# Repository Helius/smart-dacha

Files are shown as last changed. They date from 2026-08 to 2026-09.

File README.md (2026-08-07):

### Units
#### Top tank sensor
- esp32c3 with ext antenna
- uses wifi to publish self state to a mqtt broker
- no battery no outputs
- has an ultrasonic sensor and also a floating switch

#### Low tank unit
- esp32c3 with ext antenna
- reads ultrasonic sensor and controls a servo valve with sensors
- powered solely from battery (need to be optimized, or be solar powered)
- use esp-now to report self state to esp-now hub (see `valve & pump unit`)
  
#### Valve & pump unit
- esp32c3 with ext antenna
- uses wifi to publish self state and the low tank unit state to the mqtt broker
- serves also as esp-now hub for the low tank unit
- controls a servo valve with sensors and pump

### Notes
- esp-now uses the same channel as wifi - `8`, fix the channel on a router, it allows to be on both network with single esp32c3

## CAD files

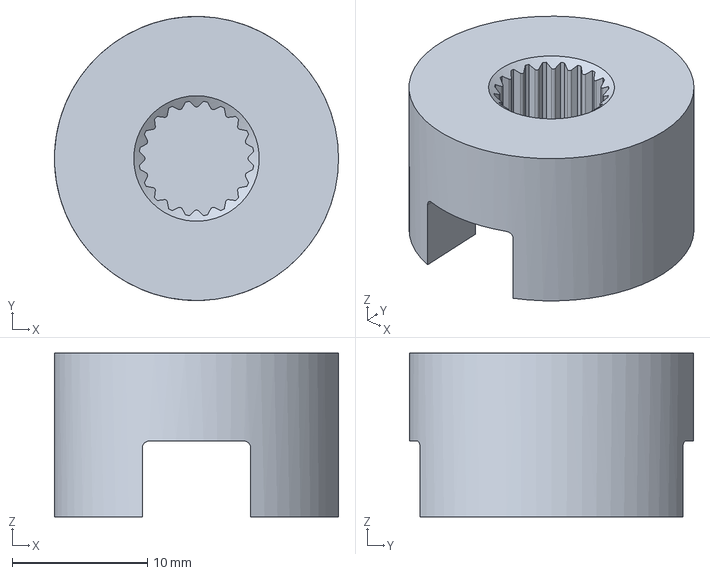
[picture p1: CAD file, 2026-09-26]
3d/servo-valve.FCStd
21.0 x 21.0 x 12.1 mm

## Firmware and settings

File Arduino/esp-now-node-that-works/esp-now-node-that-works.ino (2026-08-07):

#include <esp_now.h>
#include <WiFi.h>
#include <esp_wifi.h>
#include <ESP32Servo.h>

#include "DistanceMeter.h"

#define uS_TO_S_FACTOR 1000000ULL

#define LED_PIN 8
#define SERVO_PIN 3

#define AWAKE_BTN 2
#define ADC_PIN 4
#define SERVO_PWR_PIN 5
#define BUTTON_PIN 7
#define CLOSE_SENSOR 10
#define OPEN_SENSOR 6

uint8_t c6_mac[] = { 0x98, 0x88, 0xE0, 0x7F, 0x0A, 0x00 };  // Update this!

volatile bool replyReceived = false;
volatile int msgSend = 0;
Servo servo;

RTC_DATA_ATTR int rssi;
RTC_DATA_ATTR bool valveError = false;

float readBatteryVoltage() {
  analogSetAttenuation(ADC_11db);
  analogReadResolution(12);
  int raw = analogRead(ADC_PIN);
  return (raw / 4095.0) * 3.08 * 2.0;
}

int valveState() {
  auto open = !digitalRead(OPEN_SENSOR);
  auto close = !digitalRead(CLOSE_SENSOR);
  Serial.print("Valve sensor: ");
  Serial.print(open);
  Serial.println(close);
  if (!open && close) {
    return 0;
  } else if (open && !close) {
    return 1;
  }
  return -1;
}

// Updated callback for send status
void OnDataSent(const esp_now_send_info_t *tx_info, esp_now_send_status_t status) {

  if (status == ESP_NOW_SEND_SUCCESS) {
    msgSend = 2;
  } else {
    msgSend = 1;
  }
}

// Updated callback signature for newer API
void OnDataRecv(const esp_now_recv_info_t *info, const uint8_t *incomingData, int len) {
  char message[len + 1];
  memcpy(message, incomingData, len);
  message[len] = '\0';
  rssi = info->rx_ctrl->rssi;
  replyReceived = true;
}

bool sendAndReceive(byte *data, size_t len) {
  Serial.print("Sending: ");
  replyReceived = false;
  msgSend = 0;

  esp_err_t result = esp_now_send(c6_mac, data, len);

  if (result == ESP_OK) {
    Serial.print("OK, rssi: ");
    Serial.print(rssi);
  } else {
    Serial.print("F:");
    Serial.println(result);
    return false;
  }
  int attempts = 50;
  while ((msgSend == 0) && --attempts > 0) {
    if (msgSend == 1) {
      Serial.println(" can't send");
      return false;
    }
    delay(1);
  }

  if (msgSend != 2) {
    Serial.println(" send timeout");
    return false;
  }

  // just send

  // while (!replyReceived && attempts-- > 0) {
  //   delay(1);
  // }

  // if (!replyReceived) {
  //   Serial.println(" no reply");
  //   return false;
  // }

  return true;
}

void initRadio() {
  WiFi.mode(WIFI_STA);
  esp_wifi_set_max_tx_power(70);

  // 1. Force the Wi-Fi driver to start so channel changes take effect
  esp_wifi_start();

  // 2. Set WiFi channel to match your router (channel 8)
  esp_wifi_set_channel(8, WIFI_SECOND_CHAN_NONE);

  // 3. Verify the channel was actually set
  uint8_t primaryChan;
  wifi_second_chan_t secondChan;
  esp_wifi_get_channel(&primaryChan, &secondChan);
  Serial.print("Current Hardware Channel: ");
  Serial.println(primaryChan);

  Serial.print("C3 MAC: ");
  Serial.println(WiFi.macAddress());

  // Init ESP-NOW
  if (esp_now_init() != ESP_OK) {
    Serial.println("ESP-NOW init failed");
    return;
  }

  // Register callbacks
  esp_now_register_send_cb(OnDataSent);
  esp_now_register_recv_cb(OnDataRecv);

  // Add C6 as peer
  esp_now_peer_info_t peerInfo;
  memset(&peerInfo, 0, sizeof(peerInfo));
  memcpy(peerInfo.peer_addr, c6_mac, 6);
  peerInfo.channel = 8;
  //peerInfo.ifidx = WIFI_IF_STA;  // Changed from ESP_IF_WIFI_STA

  if (esp_now_add_peer(&peerInfo) != ESP_OK) {
    Serial.println("Failed to add C6 peer");
    return;
  }
}

void setup() {
  Serial.begin(115200);
  pinMode(LED_PIN, OUTPUT);
  pinMode(SERVO_PWR_PIN, INPUT);
  pinMode(AWAKE_BTN, INPUT_PULLUP);
  pinMode(BUTTON_PIN, INPUT_PULLUP);
  pinMode(OPEN_SENSOR, INPUT_PULLUP);
  pinMode(CLOSE_SENSOR, INPUT_PULLUP);

  esp_deep_sleep_enable_gpio_wakeup(1ULL << AWAKE_BTN, ESP_GPIO_WAKEUP_GPIO_LOW);
  Serial.println("C3 ready!");
}

void setValveOpen(bool open) {
  // TODO: check current servo valve and do nothing if it's already in state
  pinMode(SERVO_PWR_PIN, OUTPUT);
  digitalWrite(SERVO_PWR_PIN, LOW);
  Serial.print("Trun servo: ");
  Serial.println(open ? 90 : 0);
  servo.setPeriodHertz(50);
  servo.attach(SERVO_PIN, 500, 2400);
  servo.write(open ? 0 : 90);
  int attempts = 15;
  while (valveState() != (open ? 1 : 0) && attempts-- > 0) {
    Serial.println("wait servo to move");
    delay(100);
  }
  delay(100);

  if (attempts <= 0) {
    valveError = true;
  } else {
    valveError = false;
  }

  servo.detach();
  digitalWrite(SERVO_PWR_PIN, HIGH);
}

struct Packet {
  int8_t rssi;
  uint8_t bat;
  int8_t distance;
  uint8_t flags;
};

void loop() {
  static unsigned long lastSend = 0;
  digitalWrite(LED_PIN, LOW);

  for (int i = 0; i < SAMPLES_CNT; ++i) {
    measurements[i] = takeUltrasonicMeasurement();
  }

  int8_t distance = getMedian(measurements);
  uint8_t bat = readBatteryVoltage() * 10;

  // control valve
  if (distance == 0) {
    distance = -1;
  }

  if (bat < 36) {
    setValveOpen(false);
  } else {
    if (distance <= 15 && valveState() == 1) {
      setValveOpen(false);
    } else if (distance > 30 && valveState() == 0) {
      setValveOpen(true);
    }
  }

  initRadio();
  delay(10);

  Packet packet = {
    .rssi = rssi,
    .bat = bat,
    .distance = distance,
    .flags = (valveError << 1) | (valveState() == 1)
  };

  union Msg {
    Packet packet;
    byte arr[4];
  };

  Msg msg;
  msg.packet = packet;

  sendAndReceive(msg.arr, sizeof(msg.arr));

  if (valveState() == 1) {
    esp_sleep_enable_timer_wakeup(5 * uS_TO_S_FACTOR);
  } else {
    esp_sleep_enable_timer_wakeup(30 * uS_TO_S_FACTOR);
  }

  digitalWrite(LED_PIN, HIGH);
  if (!digitalRead(AWAKE_BTN)) {
    Serial.print(" Distance ");
    Serial.print(distance);

    Serial.print(", Bat ");
    Serial.print(bat);

    Serial.print(",rssi ");
    Serial.println(rssi);

    int vs = valveState();
    Serial.print("Valve state: ");
    Serial.print(vs);
    Serial.print(" valveError: ");
    Serial.print(valveError);

    delay(3000);
  } else {
    esp_deep_sleep_start();
  }

  delay(10);
}

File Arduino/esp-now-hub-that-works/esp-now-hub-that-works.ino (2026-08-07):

#include "esp32-hal-gpio.h"
#include "pins_arduino.h"
#include <esp_now.h>
#include <WiFi.h>
#include <esp_wifi.h>
#include <PubSubClient.h>
#include <ESP32Servo.h>
#include <WebServer.h>
#include <HTTPUpdateServer.h>
#include <secrets.h>

const char* mqtt_server = "192.168.0.105";

const int PUMP_RELAY_PIN = 5;
const int VALVE_SERVO_PIN = 0;
const int VALVE_OPEN_PIN = 1;
const int VALVE_CLOSE_PIN = 2;
#define RGB_BUILTIN 3

// C3 MAC address
uint8_t nodeMac[] = { 0xDC, 0x06, 0x75, 0xF6, 0xE6, 0xB0 };
uint8_t newMACAddress[] = { 0x98, 0x88, 0xE0, 0x7F, 0x0A, 0x00 };

WiFiClient espClient;
PubSubClient mqttClient(espClient);
Servo valveServo;

WebServer httpServer(80);
HTTPUpdateServer httpUpdater;

unsigned long lastPublish = 0;

int rssi;
bool valveError = false;
bool tankValveError = false;

struct Packet {
  int8_t rssi;
  uint8_t bat;
  int8_t distance;
  uint8_t flags;
};

union Msg {
  Packet packet;
  byte arr[4];
};

/**
  1 - open
  0 - closed
  -1 - error
*/
int valveState() {
  auto open = !digitalRead(VALVE_OPEN_PIN);
  auto close = !digitalRead(VALVE_CLOSE_PIN);
  Serial.print("Valve sensor: ");
  Serial.print(open);
  Serial.println(close);
  if (!open && close) {
    return 0;
  } else if (open && !close) {
    return 1;
  }
  return -1;
}


bool openValve(bool open) {
  valveServo.attach(VALVE_SERVO_PIN, 500, 2400);

  valveServo.write(open ? 0 : 90);
  int attempts = 15;
  while ((valveState() != (open ? 1 : 0)) && attempts-- > 0) {
    Serial.print("wait servo to move ");
    Serial.println(attempts);
    delay(100);
  }
  delay(100);

  if (attempts <= 0) {
    valveError = true;
    Serial.println("cant understand the valve sensors");
  } else {
    valveError = false;
    Serial.println("valve is ok");
  }
  return valveError;
}


void publishStatus() {
  char payload[128];
  snprintf(payload, sizeof(payload), "{\"pump\":\"%s\",\"valve\":\"%s\",\"rssi\":%d, \"valveError\":\"%s\"}",
           digitalRead(PUMP_RELAY_PIN) == HIGH ? "ON" : "OFF",
           valveState() == 1 ? "ON" : "OFF",
           WiFi.RSSI(),
           valveError || valveState() == -1 ? "true" : "false");

  mqttClient.publish("stat/pump-valve-unit/STATUS", payload);
  Serial.printf("[PUB] Status: %s\n", payload);
}

void publishTankStatus(int distance, int bat, uint8_t flags) {
  char payload[128];
  snprintf(payload, sizeof(payload), "{\"distance\":\"%d\",\"bat\":\"%d\", \"valve\":\"%s\", \"valveError\":\"%s\"}",
           distance, bat, (flags & 1)  ? "ON" : "OFF", (flags & (1<<1))  ? "true" : "false");
  
  mqttClient.publish("stat/low-tank-unit/STATUS", payload);
  Serial.printf("[PUB] Status: %s\n", payload);
}


// Updated callback signature for newer API
void OnDataRecv(const esp_now_recv_info_t* info, const uint8_t* incomingData, int len) {
  Msg message;
  memcpy(message.arr, incomingData, sizeof(Msg::arr));

  rssi = info->rx_ctrl->rssi;
  Serial.print("Received, rssi: ");
  Serial.println(rssi);

  // Send back the same message to the sender
  //esp_now_send(info->src_addr, incomingData, len);
  //Serial.println("Reply sent");
  Serial.printf("Receive: bat %d, level %d, flag %d, rssi %d\n",
                message.packet.bat,
                message.packet.distance,
                message.packet.flags,
                message.packet.rssi);

  tankValveError = message.packet.flags & (1 << 1);
  publishTankStatus(message.packet.distance, message.packet.bat, message.packet.flags);
}

void mqttCallback(char* topic, byte* payload, unsigned int length) {
  char message[length + 1];
  memcpy(message, payload, length);
  message[length] = '\0';

  String msg(message);
  String topicStr(topic);

  Serial.printf("[CMD] Received: topic=%s message=%s\n", topic, message);

  if (topicStr == "cmnd/pump-valve-unit/pump") {
    if (msg == "ON") {
      digitalWrite(PUMP_RELAY_PIN, HIGH);
      // on pump turn off inlet servo
      openValve(false);
    } else if (msg == "OFF") {
      digitalWrite(PUMP_RELAY_PIN, LOW);
    }
  } else if (topicStr == "cmnd/pump-valve-unit/valve") {
    if (msg == "ON") {
      openValve(true);
    } else if (msg == "OFF") {
      openValve(false);
    }
  }

  publishStatus();
}

bool reconnect() {
  int attempts = 6;
  rgbLedWrite(RGB_BUILTIN, 0, 0, 100);
  while (!mqttClient.connected() && attempts > 0) {
    --attempts;
    Serial.printf("[MQTT] Connecting to %s...\n", mqtt_server);
    if (mqttClient.connect("pumpAndValveUnit")) {
      Serial.println("[MQTT] Connected!");
      mqttClient.subscribe("cmnd/pump-valve-unit/pump");
      mqttClient.subscribe("cmnd/pump-valve-unit/valve");
      Serial.println("[MQTT] Subscribed to cmnd/pump-valve-unit/pump and cmnd/pump-valve-unit/valve");
    } else {
      Serial.printf("[MQTT] Connection failed (rc=%d), retrying in 5s...\n", mqttClient.state());
      delay(3000);
    }
  }
  if (attempts == 0) {
    return false;
  }
  return true;
}

void setupWiFiAndMQTT() {
  Serial.print("Connecting to WiFi");
  WiFi.mode(WIFI_STA);

  WiFi.begin(WIFI_SSID, WIFI_PASSWORD);

  while (WiFi.status() != WL_CONNECTED) {
    delay(500);
    Serial.print(".");
  }
  Serial.println();
  Serial.print("WiFi connected, IP: ");
  Serial.println(WiFi.localIP());

  //Setup MQTT
  mqttClient.setServer(mqtt_server, 1883);
  mqttClient.setCallback(mqttCallback);
  mqttClient.setBufferSize(512);  // Increase buffer for larger messages

  reconnect();

  httpUpdater.setup(&httpServer);
  httpServer.begin();
}
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
